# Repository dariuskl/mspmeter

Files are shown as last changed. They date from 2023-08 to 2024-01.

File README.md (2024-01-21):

# MSPmeter

This is an ongoing development for a flexible voltage & current meter based on
MSP430i2x, currently in somewhat of a proof-of-concept phase. The goal is to
have a template that can be easily adapted to replace analog or inaccurate
digital panel meters in existing power supplies or to integrate into new
designs. Accuracy-wise it would be nice to achieve .1 mV resp. .1 mA, so that
the readout can be trusted at a resolution of 1 mV resp. 1 mA.

## Planned features

- Buzzer
- Persistent calibration

## User manual

### Digital readout & indicators

### Heartbeat LED

### Buzzer

### Serial interface

9600N1

### Calibration & configuration

# Hardware

## Design notes

### Achievable accuracy

The required accuracy is 1 mV maximum error for the voltage measurement (because
we are aiming for a resolution of 10 mV) and 0.1 mA maximum error for the
current measurement (again, because we are aiming for a resolution of 1 mA).

The internal measurement circuitry of the power supply sources 1 mA for
full-scale voltage and current. To obtain 928 mV max. full-scale ADC input,
a resistor is used to drop a proportional voltage.

    R = 928 mV / 1 mA = 928 Ω

The next closest standard value *below* (we do not want to exceed that voltage)
is 910 Ω. The best readily available performer is `RN73H1JTTD9100A05` with 0.05%
tolerance and 5ppm/°C temperature drift.

That configuration yields below voltage input specification to the ADC.

    0..1 mA / (910 R ± 0.05% ± 5ppm/°C) = 910 mV ± 0.05% ± 5ppm/°C

An operating temperature range of 15 to 60 °C is a reasonable choice for such an
instrument. This yields a worst-case error range of

    0.910 * 0.000005 * (15 - 25) = −0,0000455 (~0,05 mV)
    0.910 * 0.000005 * (60 - 25) =  0,00015925 (~0,16 mV)

The final accuracy specification based on the input circuit over the full
temperature range is thus ~ 5 mV error (in terms of measured output voltage)
and ~ 0.2 mA error (in terms of measured output current).

## I/O

    ──────────────┐
             P1.0 ├─ HEARTBEAT
             P1.1 ├─
     UCA0RXD/P1.2 ├─ Rx
     UCA0TXD/P1.3 ├─ Tx
     UCB0STE/P1.4 ├─ RCLK
     UCB0CLK/P1.5 ├─ SRCLK
       TA0.2/P1.6 ├─ BUZZER
    UCB0SIMO/P1.7 ├─ SER
                  │
             P2.0 ├─ nS1_PRESSED
             P2.1 ├─ ENCODER_A
             P2.2 ├─ ENCODER_B
             P2.3 ├─
    ──────────────┘

## Adjustment procedure

A correctly adjusted unit can achieve accuracy of ???

| Parameter | VCC | Min | Typ | Max | Unit |
|---|-----|-----|-----|-----|---|
| VREF | 3 V | 1.0 | 1.2 | 1.5 | V |
| ZID | 3 V | 300 | 400 | | kΩ |

The adjustment steps have to performed in the exact order in which they are
given here and no steps may be skipped. There is no way to cancel the adjustment
half-way through.

### Input attenuator trim

If the input attenuator consists of fixed resistors, this step will be skipped.
It is not advisable to use a trimmer due to the associated temperature
coefficient, which is usually much higher than in good fixed resistors.

The input attenuator must be adjusted such that a nominal full-scale input 
yields a voltage of 928 mV on the input pins. In the range of ±928 mV is where
the MSP has the best accuracy (at a gain of 1). Otherwise, the setting is not
critical for accuracy. Just make sure not to exceed 928 mV with the range of
interest. In case of doubt, choose an input voltage in excess of the range.

1. Connect an external voltage source of the nominal full-scale input voltage to
     the input;
2. connect a voltmeter directly to the analog inputs of the MSP; then
3. adjust the trimmer for a reading of 928 mV.

### Voltage reference

To calibrate the voltage reference

1. connect a precise (how precise?) external voltage (what value?) to any (which?) input (how can I measure just the external voltage without the input circuit?);
2. measure the applied input voltage,
3. calculate actual reference voltage from theoretical value
4. check plausibility
5. apply

### Input dividers, impedance, & offset

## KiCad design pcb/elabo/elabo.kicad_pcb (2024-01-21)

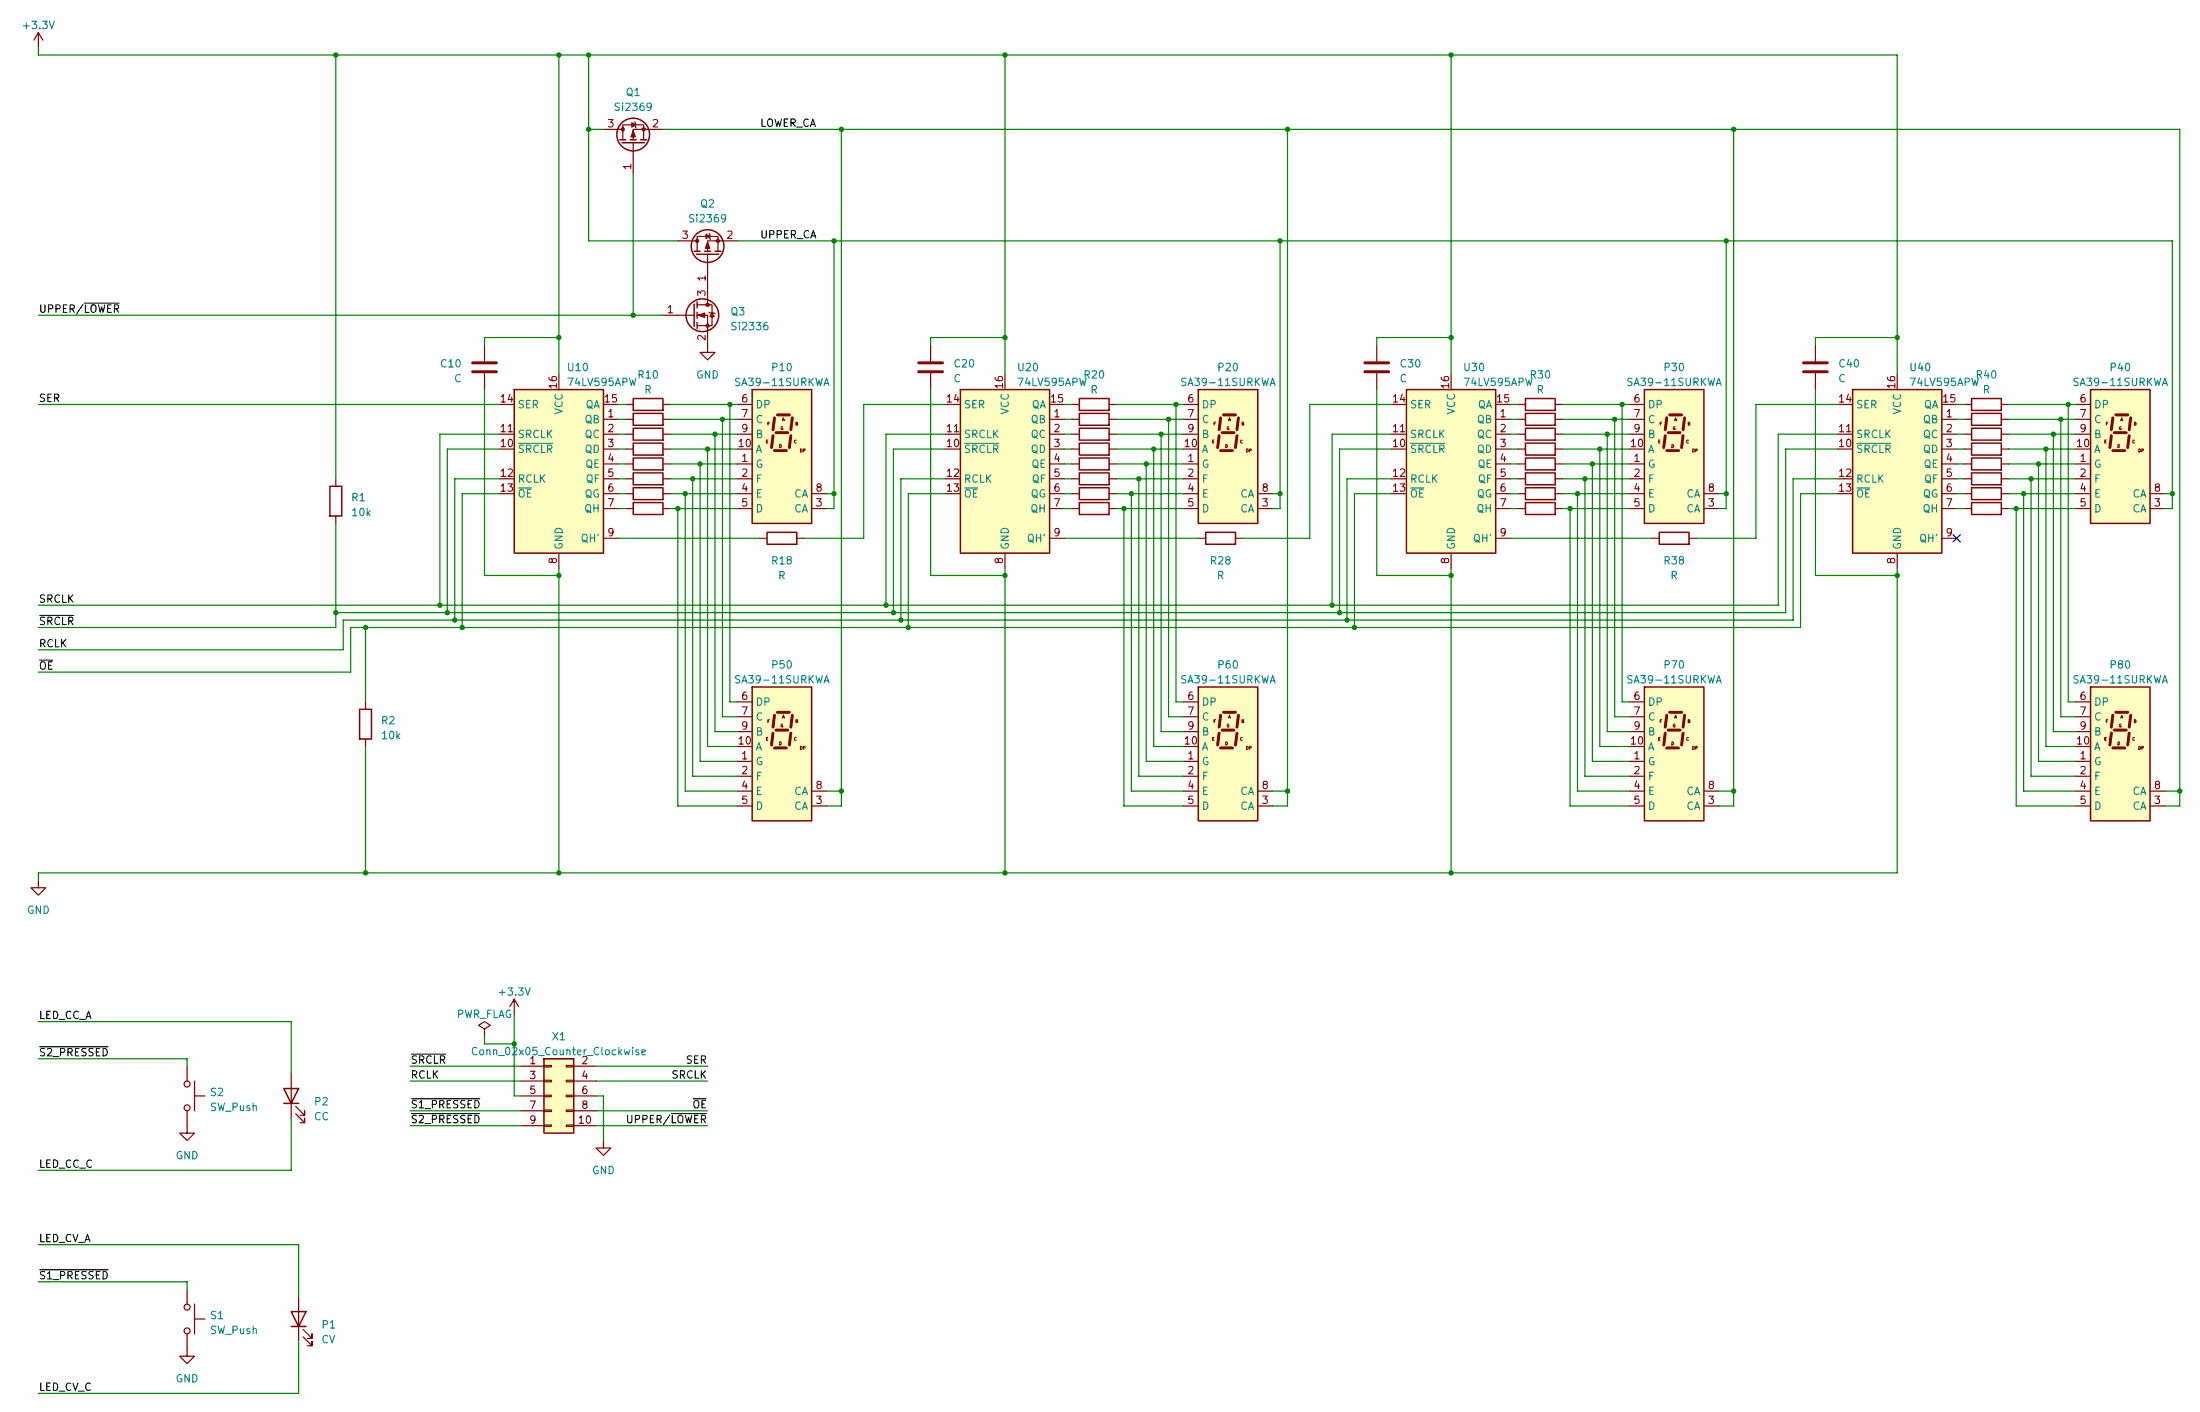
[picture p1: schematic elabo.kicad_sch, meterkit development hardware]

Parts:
C10, C20, C30, C40: C; C_0603_1608Metric
P1: CV; LED_D3.0mm_FlatTop
P2: CC; LED_D3.0mm_FlatTop
P10, P20, P30, P40, P50, P60, P70, P80: SA39-11SURKWA; Sx39-1xxxxx
Q1, Q2: Si2369; SOT-23-3
Q3: Si2336; SOT-23-3
R1, R2: 10k; R_0603_1608Metric
R10, R11, R12, R13, R14, R15, R16, R17, R18, R20, R21, R22, R23, R24, R25, R26, R27, R28, R30, R31, R32, R33, R34, R35, R36, R37, R38, R40, R41, R42, R43, R44, R45, R46, R47: R; R_0603_1608Metric
S1, S2: SW_Push; SW_PUSH_6mm_H13mm
U10, U20, U30, U40: 74LV595APW; TSSOP-16_4.4x5mm_P0.65mm
X1: Conn_02x05_Counter_Clockwise; PinHeader_2x05_P2.54mm_Vertical

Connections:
+3.3V: C10.1, C20.1, C30.1, C40.1, Q1.3 (D), Q2.3 (D), R1.1, U10.16 (VCC), U20.16 (VCC), U30.16 (VCC), U40.16 (VCC), X1.5
/LED_CC_A: P2.2 (A)
/LED_CC_C: P2.1 (K)
/LED_CV_A: P1.2 (A)
/LED_CV_C: P1.1 (K)
/LOWER_CA: P50.3 (CA), P50.8 (CA), P60.3 (CA), P60.8 (CA), P70.3 (CA), P70.8 (CA), P80.3 (CA), P80.8 (CA), Q1.2 (S)
/RCLK: U10.12 (RCLK), U20.12 (RCLK), U30.12 (RCLK), U40.12 (RCLK), X1.3
/SER: U10.14 (SER), X1.2
/SRCLK: U10.11 (SRCLK), U20.11 (SRCLK), U30.11 (SRCLK), U40.11 (SRCLK), X1.4
/UPPER_CA: P10.3 (CA), P10.8 (CA), P20.3 (CA), P20.8 (CA), P30.3 (CA), P30.8 (CA), P40.3 (CA), P40.8 (CA), Q2.2 (S)
/UPPER/~LOWER: Q1.1 (G), Q3.1 (G), X1.10
/~OE: R2.1, U10.13 (~OE), U20.13 (~OE), U30.13 (~OE), U40.13 (~OE), X1.8
/~S1_PRESSED: S1.1, X1.7
/~S2_PRESSED: S2.1, X1.9
/~SRCLR: R1.2, U10.10 (~SRCLR), U20.10 (~SRCLR), U30.10 (~SRCLR), U40.10 (~SRCLR), X1.1
GND: C10.2, C20.2, C30.2, C40.2, Q3.2 (S), R2.2, S1.2, S2.2, U10.8 (GND), U20.8 (GND), U30.8 (GND), U40.8 (GND), X1.6
unnamed: P10.10 (A), P50.10 (A), R13.2
unnamed: P10.9 (B), P50.9 (B), R12.2
unnamed: P10.7 (C), P50.7 (C), R11.2
unnamed: P10.5 (D), P50.5 (D), R17.2
unnamed: P10.6 (DP), P50.6 (DP), R10.2
unnamed: P10.4 (E), P50.4 (E), R16.2
unnamed: P10.2 (F), P50.2 (F), R15.2
unnamed: P10.1 (G), P50.1 (G), R14.2
unnamed: P20.10 (A), P60.10 (A), R23.2
unnamed: P20.9 (B), P60.9 (B), R22.2
unnamed: P20.7 (C), P60.7 (C), R21.2
unnamed: P20.5 (D), P60.5 (D), R27.2
unnamed: P20.6 (DP), P60.6 (DP), R20.2
unnamed: P20.4 (E), P60.4 (E), R26.2
unnamed: P20.2 (F), P60.2 (F), R25.2
unnamed: P20.1 (G), P60.1 (G), R24.2
unnamed: P30.10 (A), P70.10 (A), R33.2
unnamed: P30.9 (B), P70.9 (B), R32.2
unnamed: P30.7 (C), P70.7 (C), R31.2
unnamed: P30.5 (D), P70.5 (D), R37.2
unnamed: P30.6 (DP), P70.6 (DP), R30.2
unnamed: P30.4 (E), P70.4 (E), R36.2
unnamed: P30.2 (F), P70.2 (F), R35.2
unnamed: P30.1 (G), P70.1 (G), R34.2
unnamed: P40.10 (A), P80.10 (A), R43.2
unnamed: P40.9 (B), P80.9 (B), R42.2
unnamed: P40.7 (C), P80.7 (C), R41.2
unnamed: P40.5 (D), P80.5 (D), R47.2
unnamed: P40.6 (DP), P80.6 (DP), R40.2
unnamed: P40.4 (E), P80.4 (E), R46.2
unnamed: P40.2 (F), P80.2 (F), R45.2
unnamed: P40.1 (G), P80.1 (G), R44.2
unnamed: Q2.1 (G), Q3.3 (D)
unnamed: R10.1, U10.15 (QA)
unnamed: R11.1, U10.1 (QB)
unnamed: R12.1, U10.2 (QC)
unnamed: R13.1, U10.3 (QD)
unnamed: R14.1, U10.4 (QE)
unnamed: R15.1, U10.5 (QF)
unnamed: R16.1, U10.6 (QG)
unnamed: R18.1, U10.9 (QH')
unnamed: R17.1, U10.7 (QH)
unnamed: R20.1, U20.15 (QA)
unnamed: R21.1, U20.1 (QB)
unnamed: R22.1, U20.2 (QC)
unnamed: R23.1, U20.3 (QD)
unnamed: R24.1, U20.4 (QE)
unnamed: R25.1, U20.5 (QF)
unnamed: R26.1, U20.6 (QG)
unnamed: R28.1, U20.9 (QH')
unnamed: R27.1, U20.7 (QH)
unnamed: R18.2, U20.14 (SER)
unnamed: R30.1, U30.15 (QA)
unnamed: R31.1, U30.1 (QB)
unnamed: R32.1, U30.2 (QC)
unnamed: R33.1, U30.3 (QD)
unnamed: R34.1, U30.4 (QE)
unnamed: R35.1, U30.5 (QF)
unnamed: R36.1, U30.6 (QG)
unnamed: R38.1, U30.9 (QH')
unnamed: R37.1, U30.7 (QH)
unnamed: R28.2, U30.14 (SER)
unnamed: R40.1, U40.15 (QA)
unnamed: R41.1, U40.1 (QB)
unnamed: R42.1, U40.2 (QC)
unnamed: R43.1, U40.3 (QD)
unnamed: R44.1, U40.4 (QE)
unnamed: R45.1, U40.5 (QF)
unnamed: R46.1, U40.6 (QG)
unnamed: R47.1, U40.7 (QH)
unnamed: R38.2, U40.14 (SER)

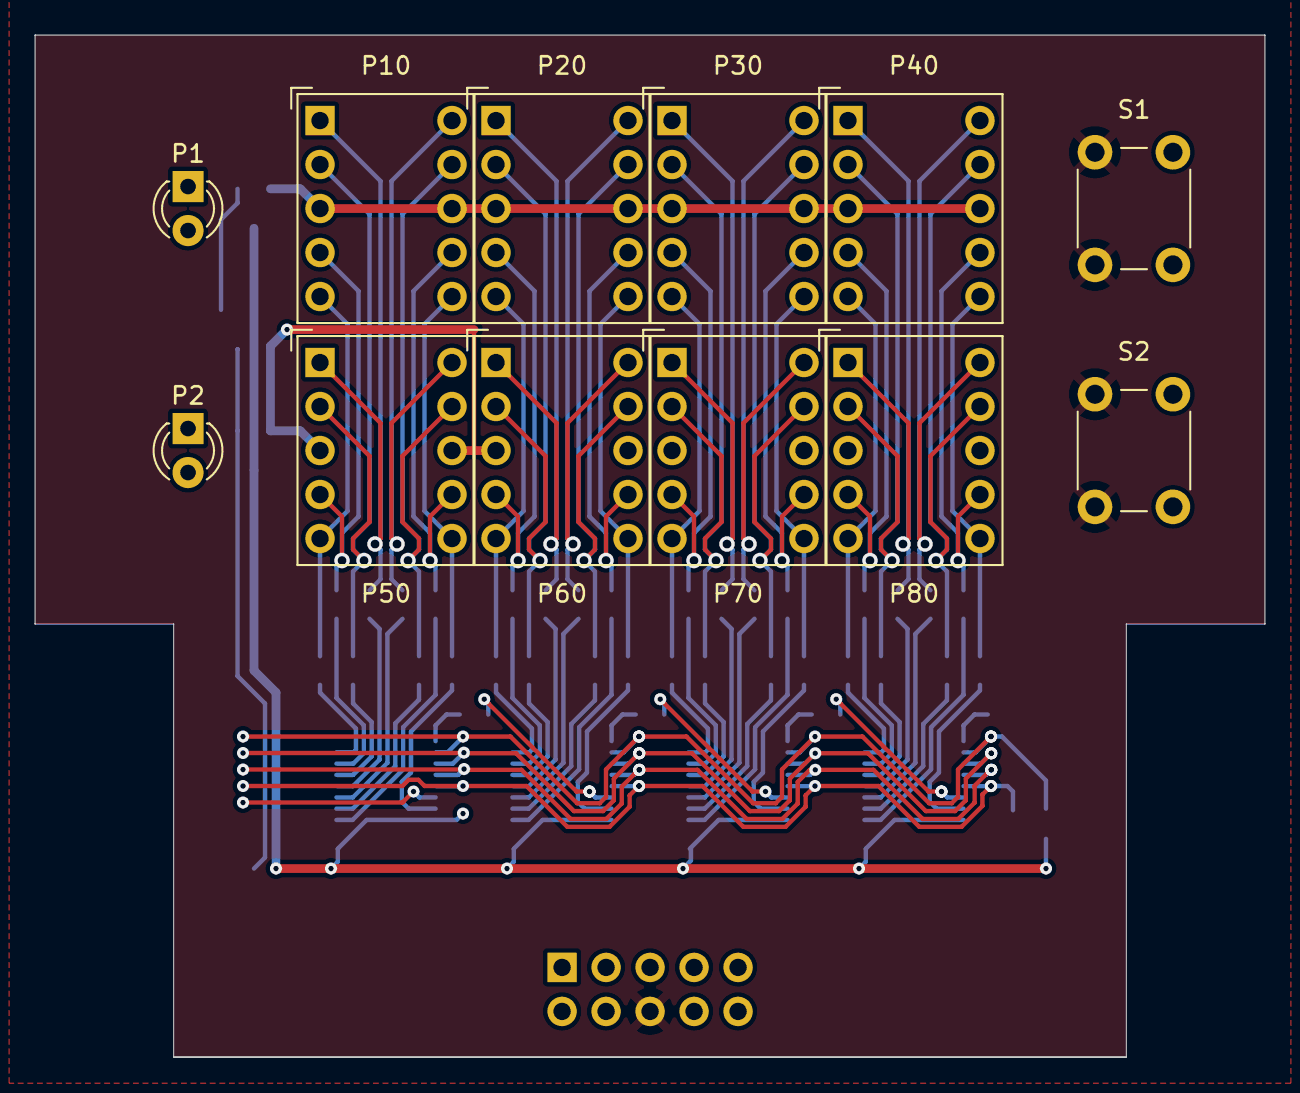
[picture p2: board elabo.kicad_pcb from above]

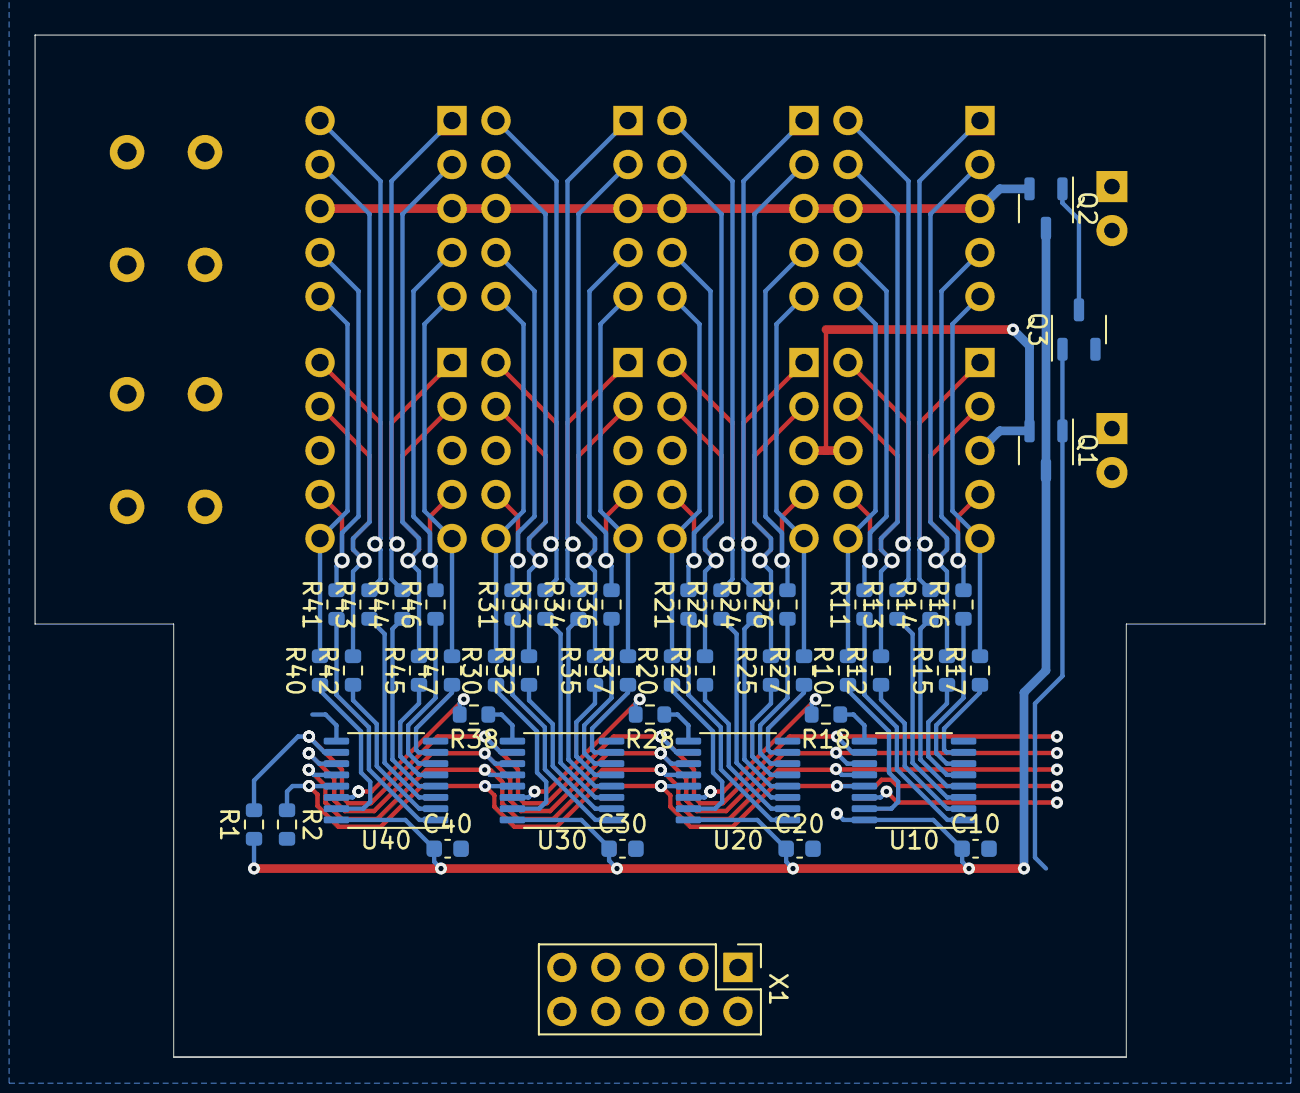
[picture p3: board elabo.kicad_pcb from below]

Board: 2 copper layers, 71.0 x 59.0 mm, 61 parts (49 on the bottom side), 83 nets.

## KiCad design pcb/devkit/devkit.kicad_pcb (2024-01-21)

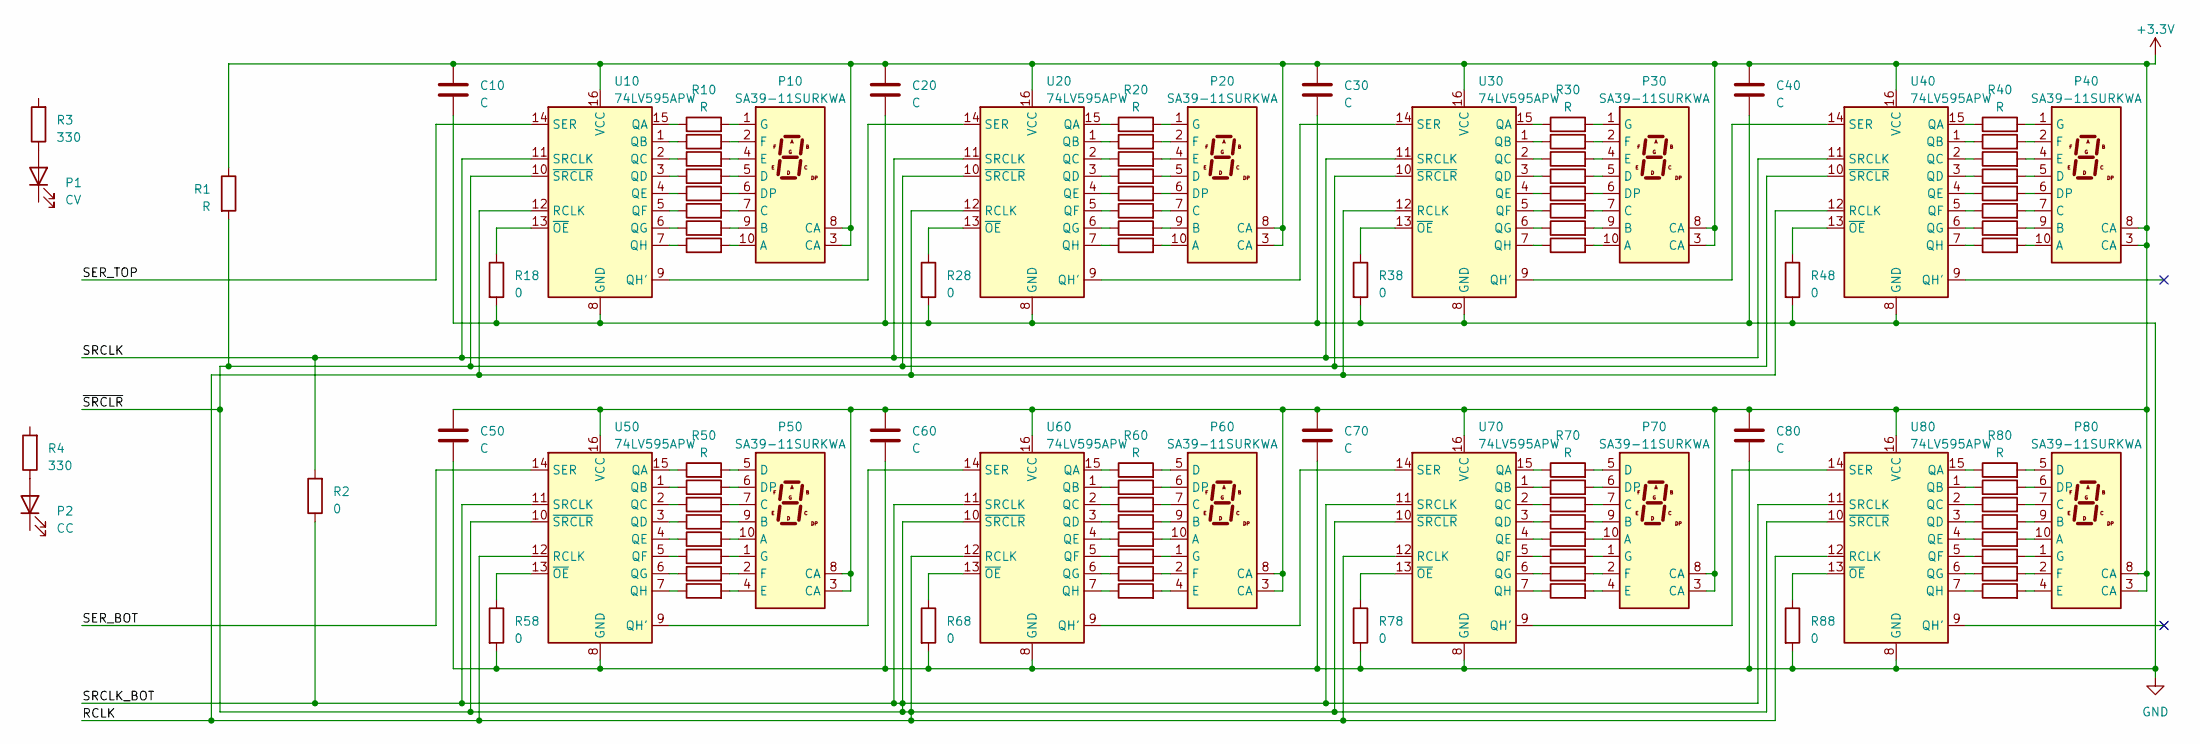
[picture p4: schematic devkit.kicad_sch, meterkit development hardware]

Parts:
C10, C20, C30, C40, C50, C60, C70, C80: C; C_0603_1608Metric
P1: CV; LED_D3.0mm_FlatTop
P2: CC; LED_D3.0mm_FlatTop
P10, P20, P30, P40, P50, P60, P70, P80: SA39-11SURKWA; Sx39-1xxxxx
R1, R10, R11, R12, R13, R14, R15, R16, R17, R20, R21, R22, R23, R24, R25, R26, R27, R30, R31, R32, R33, R34, R35, R36, R37, R40, R41, R42, R43, R44, R45, R46, R47, R50, R51, R52, R53, R54, R55, R56, R57, R60, R61, R62, R63, R64, R65, R66, R67, R70, R71, R72, R73, R74, R75, R76, R77, R80, R81, R82, R83, R84, R85, R86, R87: R; R_0603_1608Metric
R2, R18, R28, R38, R48, R58, R68, R78, R88: 0; R_0603_1608Metric
R3, R4: 330; R_0603_1608Metric
U10, U20, U30, U40, U50, U60, U70, U80: 74LV595APW; TSSOP-16_4.4x5mm_P0.65mm

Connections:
+3.3V: C10.1, C20.1, C30.1, C40.1, C50.1, C60.1, C70.1, C80.1, P10.3 (CA), P10.8 (CA), P20.3 (CA), P20.8 (CA), P30.3 (CA), P30.8 (CA), P40.3 (CA), P40.8 (CA), P50.3 (CA), P50.8 (CA), P60.3 (CA), P60.8 (CA), P70.3 (CA), P70.8 (CA), P80.3 (CA), P80.8 (CA), R1.1, U10.16 (VCC), U20.16 (VCC), U30.16 (VCC), U40.16 (VCC), U50.16 (VCC), U60.16 (VCC), U70.16 (VCC), U80.16 (VCC)
/RCLK: R1.2, R2.1, U10.10 (~SRCLR), U10.12 (RCLK), U20.10 (~SRCLR), U20.12 (RCLK), U30.10 (~SRCLR), U30.12 (RCLK), U40.10 (~SRCLR), U40.12 (RCLK), U50.10 (~SRCLR), U50.11 (SRCLK), U50.12 (RCLK), U60.10 (~SRCLR), U60.11 (SRCLK), U60.12 (RCLK), U70.10 (~SRCLR), U70.11 (SRCLK), U70.12 (RCLK), U80.10 (~SRCLR), U80.11 (SRCLK), U80.12 (RCLK)
/SER_BOT: U50.14 (SER)
/SER_TOP: U10.14 (SER)
/SRCLK: R2.2, U10.11 (SRCLK), U20.11 (SRCLK), U30.11 (SRCLK), U40.11 (SRCLK)
GND: C10.2, C20.2, C30.2, C40.2, C50.2, C60.2, C70.2, C80.2, R18.2, R28.2, R38.2, R48.2, R58.2, R68.2, R78.2, R88.2, U10.8 (GND), U20.8 (GND), U30.8 (GND), U40.8 (GND), U50.8 (GND), U60.8 (GND), U70.8 (GND), U80.8 (GND)
unnamed: P1.2 (A), R3.1
unnamed: P2.2 (A), R4.1
unnamed: P10.10 (A), R17.2
unnamed: P10.9 (B), R16.2
unnamed: P10.7 (C), R15.2
unnamed: P10.5 (D), R13.2
unnamed: P10.6 (DP), R14.2
unnamed: P10.4 (E), R12.2
unnamed: P10.2 (F), R11.2
unnamed: P10.1 (G), R10.2
unnamed: P20.10 (A), R27.2
unnamed: P20.9 (B), R26.2
unnamed: P20.7 (C), R25.2
unnamed: P20.5 (D), R23.2
unnamed: P20.6 (DP), R24.2
unnamed: P20.4 (E), R22.2
unnamed: P20.2 (F), R21.2
unnamed: P20.1 (G), R20.2
unnamed: P30.10 (A), R37.2
unnamed: P30.9 (B), R36.2
unnamed: P30.7 (C), R35.2
unnamed: P30.5 (D), R33.2
unnamed: P30.6 (DP), R34.2
unnamed: P30.4 (E), R32.2
unnamed: P30.2 (F), R31.2
unnamed: P30.1 (G), R30.2
unnamed: P40.10 (A), R47.2
unnamed: P40.9 (B), R46.2
unnamed: P40.7 (C), R45.2
unnamed: P40.5 (D), R43.2
unnamed: P40.6 (DP), R44.2
unnamed: P40.4 (E), R42.2
unnamed: P40.2 (F), R41.2
unnamed: P40.1 (G), R40.2
unnamed: P50.10 (A), R54.2
unnamed: P50.9 (B), R53.2
unnamed: P50.7 (C), R52.2
unnamed: P50.5 (D), R50.2
unnamed: P50.6 (DP), R51.2
unnamed: P50.4 (E), R57.2
unnamed: P50.2 (F), R56.2
unnamed: P50.1 (G), R55.2
unnamed: P60.10 (A), R64.2
unnamed: P60.9 (B), R63.2
unnamed: P60.7 (C), R62.2
unnamed: P60.5 (D), R60.2
unnamed: P60.6 (DP), R61.2
unnamed: P60.4 (E), R67.2
unnamed: P60.2 (F), R66.2
unnamed: P60.1 (G), R65.2
unnamed: P70.10 (A), R74.2
unnamed: P70.9 (B), R73.2
unnamed: P70.7 (C), R72.2
unnamed: P70.5 (D), R70.2
unnamed: P70.6 (DP), R71.2
unnamed: P70.4 (E), R77.2
unnamed: P70.2 (F), R76.2
unnamed: P70.1 (G), R75.2
unnamed: P80.10 (A), R84.2
unnamed: P80.9 (B), R83.2
unnamed: P80.7 (C), R82.2
unnamed: P80.5 (D), R80.2
unnamed: P80.6 (DP), R81.2
unnamed: P80.4 (E), R87.2
unnamed: P80.2 (F), R86.2
unnamed: P80.1 (G), R85.2
unnamed: R10.1, U10.15 (QA)
unnamed: R11.1, U10.1 (QB)
unnamed: R12.1, U10.2 (QC)
unnamed: R13.1, U10.3 (QD)
unnamed: R14.1, U10.4 (QE)
unnamed: R15.1, U10.5 (QF)
unnamed: R16.1, U10.6 (QG)
unnamed: U10.9 (QH'), U20.14 (SER)
unnamed: R17.1, U10.7 (QH)
unnamed: R18.1, U10.13 (~OE)
unnamed: R20.1, U20.15 (QA)
unnamed: R21.1, U20.1 (QB)
unnamed: R22.1, U20.2 (QC)
unnamed: R23.1, U20.3 (QD)
unnamed: R24.1, U20.4 (QE)
unnamed: R25.1, U20.5 (QF)
unnamed: R26.1, U20.6 (QG)
unnamed: U20.9 (QH'), U30.14 (SER)
unnamed: R27.1, U20.7 (QH)
unnamed: R28.1, U20.13 (~OE)
unnamed: R30.1, U30.15 (QA)
unnamed: R31.1, U30.1 (QB)
unnamed: R32.1, U30.2 (QC)
unnamed: R33.1, U30.3 (QD)
unnamed: R34.1, U30.4 (QE)
unnamed: R35.1, U30.5 (QF)
unnamed: R36.1, U30.6 (QG)
unnamed: U30.9 (QH'), U40.14 (SER)
unnamed: R37.1, U30.7 (QH)
unnamed: R38.1, U30.13 (~OE)
unnamed: R40.1, U40.15 (QA)
unnamed: R41.1, U40.1 (QB)
unnamed: R42.1, U40.2 (QC)
unnamed: R43.1, U40.3 (QD)
unnamed: R44.1, U40.4 (QE)
unnamed: R45.1, U40.5 (QF)
unnamed: R46.1, U40.6 (QG)
unnamed: R47.1, U40.7 (QH)
unnamed: R48.1, U40.13 (~OE)
unnamed: R50.1, U50.15 (QA)
unnamed: R51.1, U50.1 (QB)
unnamed: R52.1, U50.2 (QC)
unnamed: R53.1, U50.3 (QD)
unnamed: R54.1, U50.4 (QE)
unnamed: R55.1, U50.5 (QF)
unnamed: R56.1, U50.6 (QG)
unnamed: U50.9 (QH'), U60.14 (SER)
unnamed: R57.1, U50.7 (QH)
unnamed: R58.1, U50.13 (~OE)
unnamed: R60.1, U60.15 (QA)
unnamed: R61.1, U60.1 (QB)
unnamed: R62.1, U60.2 (QC)
unnamed: R63.1, U60.3 (QD)
unnamed: R64.1, U60.4 (QE)
unnamed: R65.1, U60.5 (QF)
unnamed: R66.1, U60.6 (QG)
unnamed: U60.9 (QH'), U70.14 (SER)
unnamed: R67.1, U60.7 (QH)
unnamed: R68.1, U60.13 (~OE)
unnamed: R70.1, U70.15 (QA)
unnamed: R71.1, U70.1 (QB)
unnamed: R72.1, U70.2 (QC)
unnamed: R73.1, U70.3 (QD)
unnamed: R74.1, U70.4 (QE)
unnamed: R75.1, U70.5 (QF)
unnamed: R76.1, U70.6 (QG)
unnamed: U70.9 (QH'), U80.14 (SER)
unnamed: R77.1, U70.7 (QH)
unnamed: R78.1, U70.13 (~OE)
unnamed: R80.1, U80.15 (QA)
unnamed: R81.1, U80.1 (QB)
unnamed: R82.1, U80.2 (QC)
unnamed: R83.1, U80.3 (QD)
unnamed: R84.1, U80.4 (QE)
unnamed: R85.1, U80.5 (QF)
unnamed: R86.1, U80.6 (QG)
unnamed: R87.1, U80.7 (QH)
unnamed: R88.1, U80.13 (~OE)

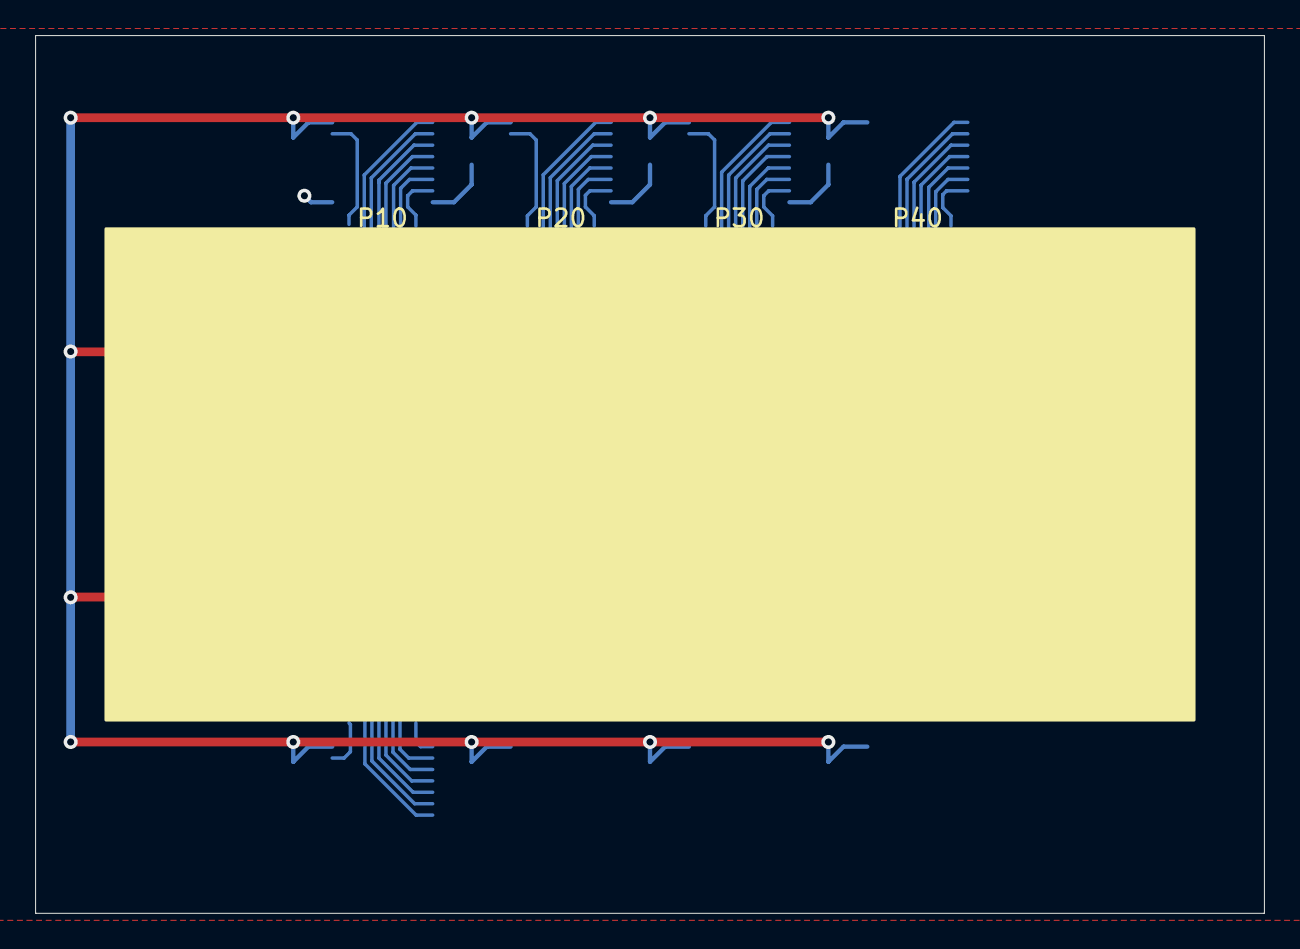
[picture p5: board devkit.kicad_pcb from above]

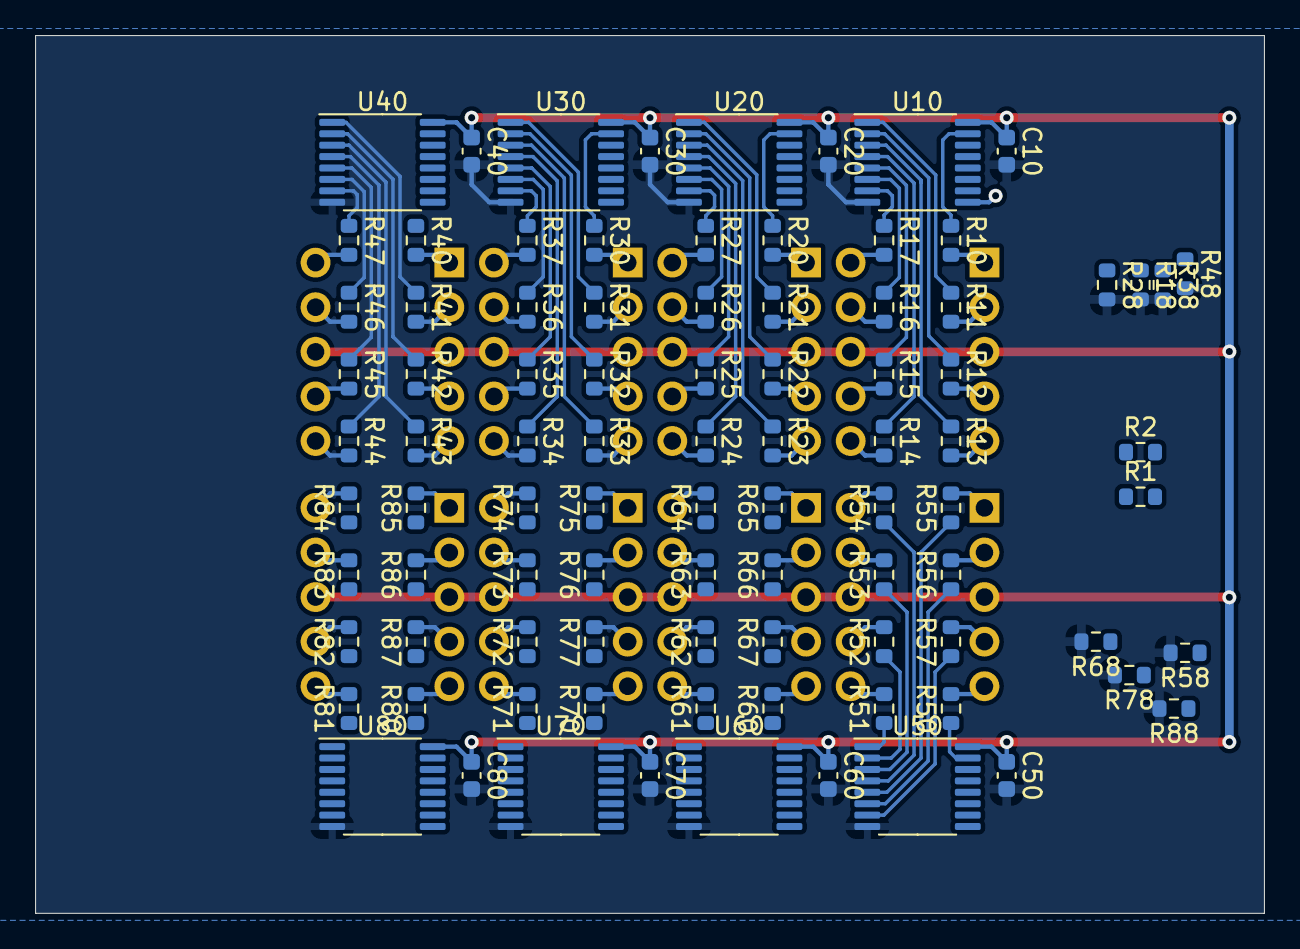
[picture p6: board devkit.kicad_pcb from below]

Board: 2 copper layers, 70.0 x 50.0 mm, 98 parts (90 on the bottom side), 146 nets.

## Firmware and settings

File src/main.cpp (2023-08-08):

// Meter Firmware / Darius Kellermann <kellermann@protonmail.com>

#include "meter.hpp"
#include "msp/uart.hpp"
#include "msp430i2.hpp"

namespace {

  auto upper_text_buffer_ = Array<char, 6>{"00.00"};
  auto lower_text_buffer_ = Array<char, 6>{"0.000"};

  auto meter_ = meter::Meter{upper_text_buffer_, lower_text_buffer_};
  auto readout_ = meter::Readout{};

  [[gnu::interrupt]] void default_isr() {}

  [[gnu::interrupt]] void eusci_a0_rxtx_isr() {
    switch (msp430i2::UCA0::interrupt_vector()) {
    default:
      break;
    case msp430i2::UCIVx::RxBufferFull:
      if (meter_.eusci_a0_rx_buffer_full_isr()) {
        msp430::stay_awake();
      }
      break;
    case msp430i2::UCIVx::TxBufferEmpty:
      if (meter_.eusci_a0_tx_buffer_empty_isr()) {
        msp430::stay_awake();
      }
      break;
    }
  }

  [[gnu::interrupt]] void eusci_b0_rxtx_isr() {
    switch (msp430i2::UCB0::interrupt_vector()) {
    default:
      break;
    case msp430i2::UCIVx::TxBufferEmpty:
      readout_.on_tx_buffer_empty();
      break;
    }
  }

  [[gnu::interrupt]] void sd24_isr() {
    switch (msp430i2::SD24::interrupt_vector()) {
    default:
      break;
    case msp430i2::SD24IVx::SD24_0:
      if (meter_.sd24_1_conversion_done_isr()) {
        msp430::stay_awake();
      }
      break;
    }
  }

  [[gnu::interrupt]] void io_port_p2_isr() {
    switch (load(msp430i2::P2IV)) {
    default:
      break;
    case msp430i2::PxIV::Px_0:
      if (meter_.on_s1_down()) {
        msp430::stay_awake();
      }
      break;
    case msp430i2::PxIV::Px_1: {
      msp430i2::Digital_io::toggle_interrupt_edge(msp430i2::PA::P2_1);
      meter_.update_encoder();
      break;
    }
    case msp430i2::PxIV::Px_2: {
      msp430i2::Digital_io::toggle_interrupt_edge(msp430i2::PA::P2_2);
      meter_.update_encoder();
      break;
    }
    }
  }

  constexpr auto vtable [[gnu::used,
                          gnu::section(".vectors")]] = Array<void (*)(), 32>{
      {nullptr,           nullptr,           nullptr,     nullptr,
       nullptr,           nullptr,           nullptr,     nullptr,
       nullptr,           nullptr,           nullptr,     nullptr,
       nullptr,           nullptr,           nullptr,     nullptr,
       default_isr,       io_port_p2_isr,    default_isr, default_isr,
       default_isr,       default_isr,       default_isr, sd24_isr,
       eusci_b0_rxtx_isr, eusci_a0_rxtx_isr, default_isr, default_isr,
       default_isr,       default_isr,       default_isr, msp430i2::on_reset}};

  [[gnu::section(".calibration_data")]] auto cal = meter::Calibration_constants{
      meter::default_calibration};

} // namespace

int main() {
  msp430::Watchdog_timer::hold();
  if (!msp430i2::calibrate_peripherals()) {
    error(meter::Meter_status::InformationMemoryIntegrity);
  }

  msp430i2::Digital_io::configure_as_output(
      meter::heartbeat_pin | meter::buzzer_pin | msp430i2::PA::P2_3);
  msp430i2::Digital_io::set(meter::heartbeat_pin | msp430i2::PA::P2_3);
  msp430i2::Digital_io::configure_interrupt(
      meter::ns1_pressed_pin
          // set next edge depending on current pin state for encoder
          | (msp430i2::Digital_io::get()
             & (meter::encoder_a_pin | meter::encoder_b_pin)),
      meter::ns1_pressed_pin | meter::encoder_a_pin | meter::encoder_b_pin);

  msp430::SPI<msp430i2::UCB0>::configure();
  msp430::UART<msp430i2::UCA0>::configure();

  msp430i2::Digital_io::select_function(meter::rx_pin          // UCA0RXD
                                            | meter::tx_pin    // UCA0TXD
                                            | meter::rclk_pin  // UCB0STE
                                            | meter::srclk_pin // UCB0CLK
                                            | meter::ser_pin,  // UCB0SIMO
                                        u8{1U});

  meter::AD_converter::init();

  meter_.update_encoder();

  msp430::enable_interrupts();

  while (true) {
    meter_.set_calibration(cal);

    auto status = meter::Meter_status::OK;

    for (auto op =
             meter::Normal_operation{upper_text_buffer_, lower_text_buffer_,
                                     meter_, readout_};
         status == meter::Meter_status::OK; status = op()) {
      msp430i2::Digital_io::clear(meter::heartbeat_pin);
      msp430::go_to_sleep();
      msp430i2::Digital_io::set(meter::heartbeat_pin);
    }

    switch (status) {
    case meter::Meter_status::InformationMemoryIntegrity:
    case meter::Meter_status::ConversionOverflow:
    case meter::Meter_status::SerialBusy:
    case meter::Meter_status::StringConversionFailure:
      meter::error(status);
      break;
    case meter::Meter_status::StoreCalibration: {
      auto fmc = msp430i2::Flash_memory_controller{msp430i2::dco_frequency_Hz};
      fmc.erase_segment(&cal);
      fmc.write(cal, meter_.cal());
      break;
    }
    case meter::Meter_status::OK:
      break;
    }
  }
}

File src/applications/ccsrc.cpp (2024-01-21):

// Meter Firmware / Darius Kellermann <kellermann@proton.me>

/* Firmware for a constant-current source meter providing current and voltage
 * drop over load readout on a SH1107-based OLED display.
 */

#include "drivers/sh1107.hpp"
#include "msp/i2c.hpp"
#include "msp430.hpp"
#include "msp430i2.hpp"

namespace {

  constexpr auto heartbeat_pin = msp430i2::PA::P1_0;
  constexpr auto rx_pin = msp430i2::PA::P1_2;
  constexpr auto tx_pin = msp430i2::PA::P1_3;
  constexpr auto buzzer_pin = msp430i2::PA::P1_5;
  constexpr auto scl_pin = msp430i2::PA::P1_6;
  constexpr auto sda_pin = msp430i2::PA::P1_7;
  constexpr auto ns1_pressed_pin = msp430i2::PA::P2_0;
  constexpr auto encoder_a_pin = msp430i2::PA::P2_1;
  constexpr auto encoder_b_pin = msp430i2::PA::P2_2;

  auto display_port =
      msp430::I2C_master<msp430i2::UCB0, meter::SH1107_i2c_address>{};
  auto display_driver = meter::SH1107{display_port};
  auto display_buffer = meter::Draw_buffer<128, 64>{};

  void update_display() { display_driver.send_data(); }

  [[noreturn]] void run() {
    display_port.configure();
    display_driver.init();

    msp430::enable_interrupts();

    while (true) {
      update_display();
    }
  }

  [[gnu::interrupt]] void default_isr() {}

  [[gnu::interrupt]] void eusci_b0_rxtx_isr() {
    switch (msp430i2::UCB0::interrupt_vector()) {
    default:
      break;
    case msp430i2::UCIVx::TxBufferEmpty:
      display_port.transmit_next();
      break;
    }
  }

  constexpr auto vtable
      [[gnu::used, gnu::section(".vectors")]] = Array<void (*)(), 32>{
          {nullptr,           nullptr,     nullptr,     nullptr,
           nullptr,           nullptr,     nullptr,     nullptr,
           nullptr,           nullptr,     nullptr,     nullptr,
           nullptr,           nullptr,     nullptr,     nullptr,
           default_isr,       default_isr, default_isr, default_isr,
           default_isr,       default_isr, default_isr, default_isr,
           eusci_b0_rxtx_isr, default_isr, default_isr, default_isr,
           default_isr,       default_isr, default_isr, msp430i2::on_reset}};

} // namespace

int main() {
  msp430::Watchdog_timer::hold();
  if (msp430i2::calibrate_peripherals()) {
    run();
  }
}

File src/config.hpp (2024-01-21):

// Meter Firmware / Darius Kellermann <kellermann@proton.me>

#ifndef MSPMETER_CONFIG_HPP
#define MSPMETER_CONFIG_HPP

#include "calibration.hpp"
#include "msp430i2.hpp"

namespace meter {

  constexpr auto used_channels = 4;

  /// The number of samples, which are accumulated in the background and
  /// averaged to obtain one "reading" that is displayed to the user.
  constexpr auto number_of_oversamples = 256;

  constexpr auto default_calibration =
      Array<Channel_calibration, used_channels>{
          {{5'000'000, 30'000'000, msp430i2::SD24::full_scale, 0},
           {1'000'000, 1'000'000, msp430i2::SD24::full_scale, 0},
           {5'000'000, 30'000'000, msp430i2::SD24::full_scale, 0},
           {1'000'000, 1'000'000, msp430i2::SD24::full_scale, 0}}};

  constexpr auto heartbeat_pin = msp430i2::PA::P1_0;
  constexpr auto rx_pin = msp430i2::PA::P1_2;
  constexpr auto tx_pin = msp430i2::PA::P1_3;
  constexpr auto rclk_pin = msp430i2::PA::P1_4;
  constexpr auto srclk_pin = msp430i2::PA::P1_5;
  constexpr auto buzzer_pin = msp430i2::PA::P1_6;
  constexpr auto ser_pin = msp430i2::PA::P1_7;
  constexpr auto ns1_pressed_pin = msp430i2::PA::P2_0;
  constexpr auto encoder_a_pin = msp430i2::PA::P2_1;
  constexpr auto encoder_b_pin = msp430i2::PA::P2_2;

} // namespace meter

#endif // MSPMETER_CONFIG_HPP

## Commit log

2023-07-06 implemented gain calibration
    This also reduces the computational effort by incorporating the conversion
    from ADC result to voltage into the calibration.
2023-07-10 calibration can be stored to flash now
2023-07-12 fix digital outputs
    The default direction of the PADIR register is input.
    [main.cpp]
2023-08-08 improve calibration and use all available channels
